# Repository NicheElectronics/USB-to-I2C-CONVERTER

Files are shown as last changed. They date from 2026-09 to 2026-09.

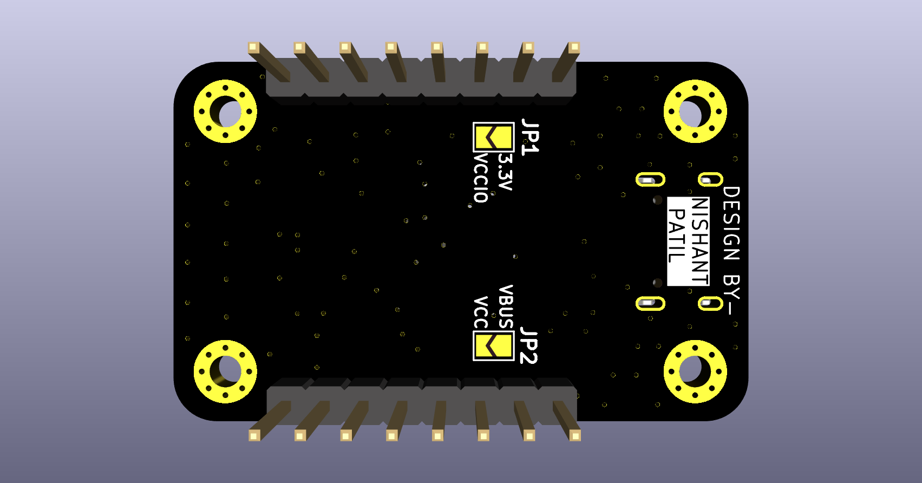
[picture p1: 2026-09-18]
hardware/pcb-design/renders/PCB-3D-Bottom.png

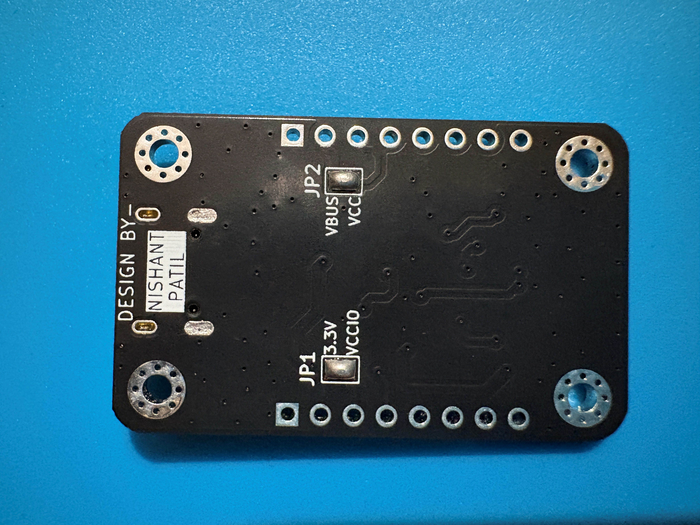
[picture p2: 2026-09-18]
validation/hardware/Assembled-PCB-Bottom.png

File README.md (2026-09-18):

# USB-to-I²C Converter | FT201X

A compact USB interface for an embedded system with an I²C master. The board uses an **FTDI FT201X** to exchange data between a USB host and a microcontroller or FPGA over I²C. Its USB Type-C connector provides the USB 2.0 connection to the computer.

> **Direction matters:** The FT201X is an **I²C slave**. It cannot act as an I²C master to scan or read sensors directly. Your microcontroller or FPGA initiates every I²C transfer.

## Project status

The PCB has been assembled and tested, according to the project notes. Specific measurements, firmware, and test logs have not been included here.

## How it works

```mermaid
flowchart TD
    PC["Computer / USB host"] <-->|"USB 2.0"| FT["FT201X · I²C slave"]
    FT <-->|"SDA + SCL"| MCU["MCU or FPGA · I²C master"]
    MCU <-->|"Shared I²C bus"| SENSOR["Other I²C devices"]
```

The master can address the FT201X and other slaves on the same bus, provided each slave has a unique address and the devices share compatible I/O levels. For example, to bring sensor readings to a PC, the MCU reads the sensor and writes the result to the FT201X; the FT201X sends those bytes over USB. The PC can send commands in the other direction for the MCU to read.

This is a **USB connection for an I²C-master system**, not a PC-controlled general-purpose I²C master adapter.

## Hardware overview

| Item | Implementation / purpose |
| --- | --- |
| Bridge | FTDI FT201X, USB 2.0 full speed to I²C slave |
| USB connector | USB Type-C, wired for USB 2.0 device operation |
| USB protection | ESD protection on D+ and D−; 27 Ω series resistors in the USB data paths |
| I²C connection | SDA and SCL with pull-up resistors; MCU/FPGA provides the clock |
| I/O supply | VCCIO sets the FT201X interface voltage; match it to the I²C bus |
| Other signals | Reset and configurable CBUS signals available on the board |
| Power | USB bus power with local decoupling and bulk capacitance |

The USB Type-C connection uses both orientations of D+ and D− and separate pull-down resistors on CC1 and CC2. Check the schematic for exact values, connector pinout, headers, and power options before connecting external hardware.

## I²C address and speed

- The FT201X factory-default **7-bit address is `0x22`**. An MCU library normally expects this 7-bit value, not the shifted address bytes (`0x44` for write and `0x45` for read).
- The address is configurable in FT201X nonvolatile settings, so check the programmed configuration if a scanner does not find `0x22`.
- Start bus bring-up at **100 kHz**; try **400 kHz** after basic transfers work. The FT201X supports faster I²C modes, but the selected rate and pull-ups must also work for every other device and the bus wiring.
- The USB serial port baud setting does **not** set the I²C clock. The I²C master generates SCL.

## Bring-up

1. With power off, check for shorts between supply and ground and confirm the intended VCCIO and pull-up voltage.
2. Connect USB and confirm the FT201X enumerates on the computer. Use FTDI's **FT_PROG** if you need to inspect its programmed settings.
3. Connect a common ground, SDA, and SCL to an I²C-master MCU. Avoid connecting an incompatible-voltage bus directly.
4. Set the MCU bus to 100 kHz and scan for the configured FT201X address (`0x22` by default).
5. Test bytes in **both** directions: PC → FT201X → MCU and MCU → FT201X → PC. Use the FT201X transfer protocol in the datasheet when writing firmware.
6. Add any sensors after the bridge works; check that their addresses do not conflict.

For PC-side testing, install the applicable FTDI driver. If the device appears as a virtual COM port, a serial terminal or `pyserial` can send and receive bytes. Define framing and commands in the MCU firmware; the FT201X does not automatically turn sensor data into text lines.

## If communication fails

| Symptom | Check |
| --- | --- |
| No USB device | USB cable and connector, VBUS, supply rails, reset, D+/D− wiring and ESD parts |
| No I²C acknowledgement | Master mode, common ground, SDA/SCL wiring, pull-ups, VCCIO, configured address |
| Intermittent transfers | Pull-up strength, bus capacitance, clock rate and shared-device loading |
| USB works but no sensor data | MCU firmware, FT201X read/write sequence and sensor address |

## Reference

- [FTDI FT201X product documentation](https://ftdichip.com/products/ft201xq/)

## Author

**Nishant Patil**

No license has been specified for the project files. Add a license file when you decide how others may use the design.

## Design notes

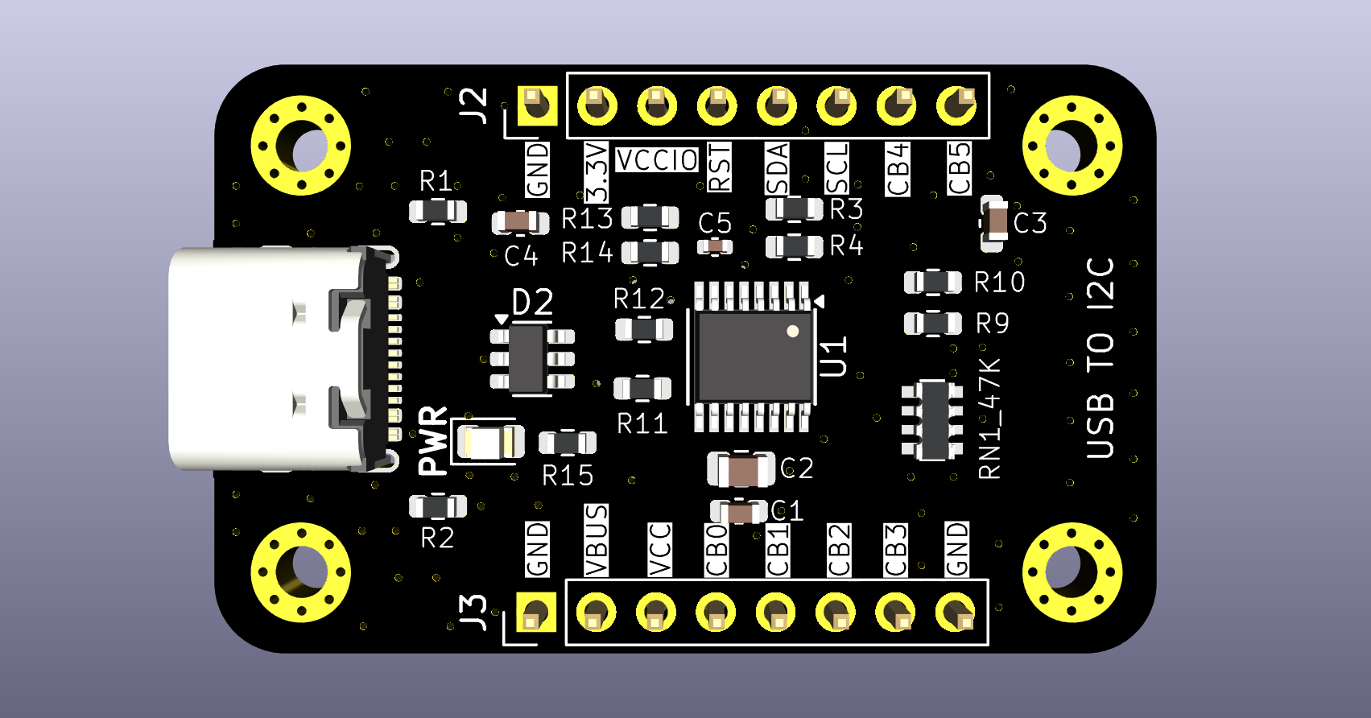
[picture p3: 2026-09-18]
hardware/pcb-design/renders/PCB-3D-Top.png

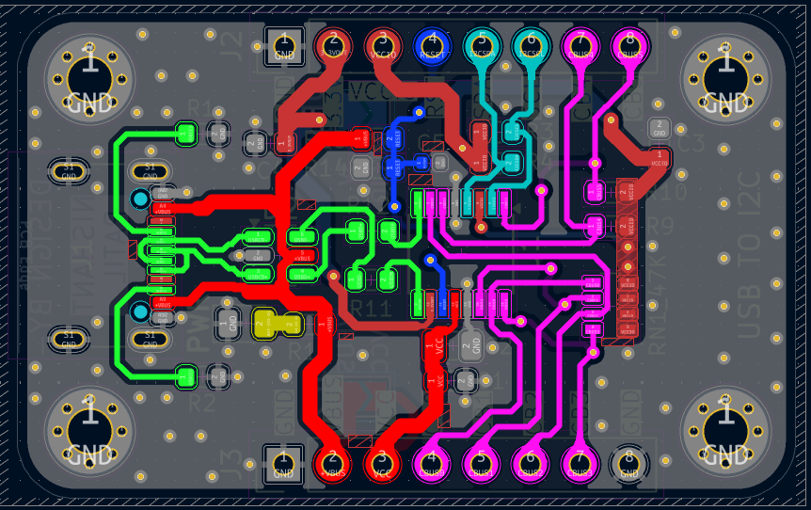
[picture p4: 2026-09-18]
hardware/pcb-design/layers/L1-Top-Signal-Power-GND-Pour.png

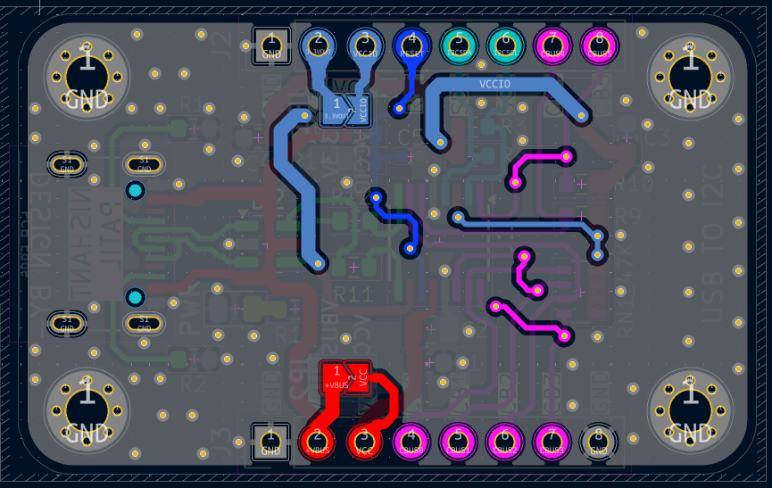
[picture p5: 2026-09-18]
hardware/pcb-design/layers/L2-Bottom-Signal-Power-GND-Pour.png

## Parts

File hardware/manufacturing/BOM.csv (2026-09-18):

Reference | Qty | Value | DNP | Exclude from BOM | Exclude from Board | Footprint | Datasheet
C1,C3,C4 | 3 | 0.1u |  |  |  | Capacitor_SMD:C_0603_1608Metric | ~
C2 | 1 | 4.7u |  |  |  | Capacitor_SMD:C_0805_2012Metric | ~
C5 | 1 | 10n |  |  |  | Capacitor_SMD:C_0402_1005Metric | ~
D1 | 1 | LED |  |  |  | LED_SMD:LED_0805_2012Metric | ~
D2 | 1 | USBLC6-2SC6 |  |  |  | Package_TO_SOT_SMD:SOT-23-6 | https://www.st.com/resource/en/datasheet/usblc6-2.pdf
H1,H2,H3,H4 | 4 | M2 |  | Excluded from BOM |  | MountingHole:MountingHole_2.2mm_M2_Pad_Via | ~
J1 | 1 | USB_C_Receptacle_USB2.0_16P |  |  |  | Connector_USB:USB_C_Receptacle_GCT_USB4105-xx-A_16P_TopMnt_Horizontal | https://www.usb.org/sites/default/files/documents/usb_type-c.zip
J2,J3 | 2 | Conn_01x08_Pin |  |  |  | Connector_PinHeader_2.54mm:PinHeader_1x08_P2.54mm_Vertical | ~
JP1,JP2 | 2 | Jumper_2_Open |  |  |  | Jumper:SolderJumper-2_P1.3mm_Open_TrianglePad1.0x1.5mm | ~
R1,R2 | 2 | 5K1 |  |  |  | Resistor_SMD:R_0603_1608Metric | ~
R3,R4 | 2 | 1K |  |  |  | Resistor_SMD:R_0603_1608Metric | ~
R9,R10 | 2 | 47K |  |  |  | Resistor_SMD:R_0603_1608Metric | ~
R11,R12 | 2 | 27R |  |  |  | Resistor_SMD:R_0603_1608Metric | ~
R13 | 1 | 10K |  |  |  | Resistor_SMD:R_0603_1608Metric | ~
R14 | 1 | 15K |  |  |  | Resistor_SMD:R_0603_1608Metric | ~
R15 | 1 | 270R |  |  |  | Resistor_SMD:R_0603_1608Metric | ~
RN1 | 1 | R_47K |  |  |  | Resistor_SMD:R_Array_Convex_4x0603 | ~
U1 | 1 | FT201XS |  |  |  | Package_SO:SSOP-16_3.9x4.9mm_P0.635mm | https://www.ftdichip.com/Support/Documents/DataSheets/ICs/DS_FT201X.pdf

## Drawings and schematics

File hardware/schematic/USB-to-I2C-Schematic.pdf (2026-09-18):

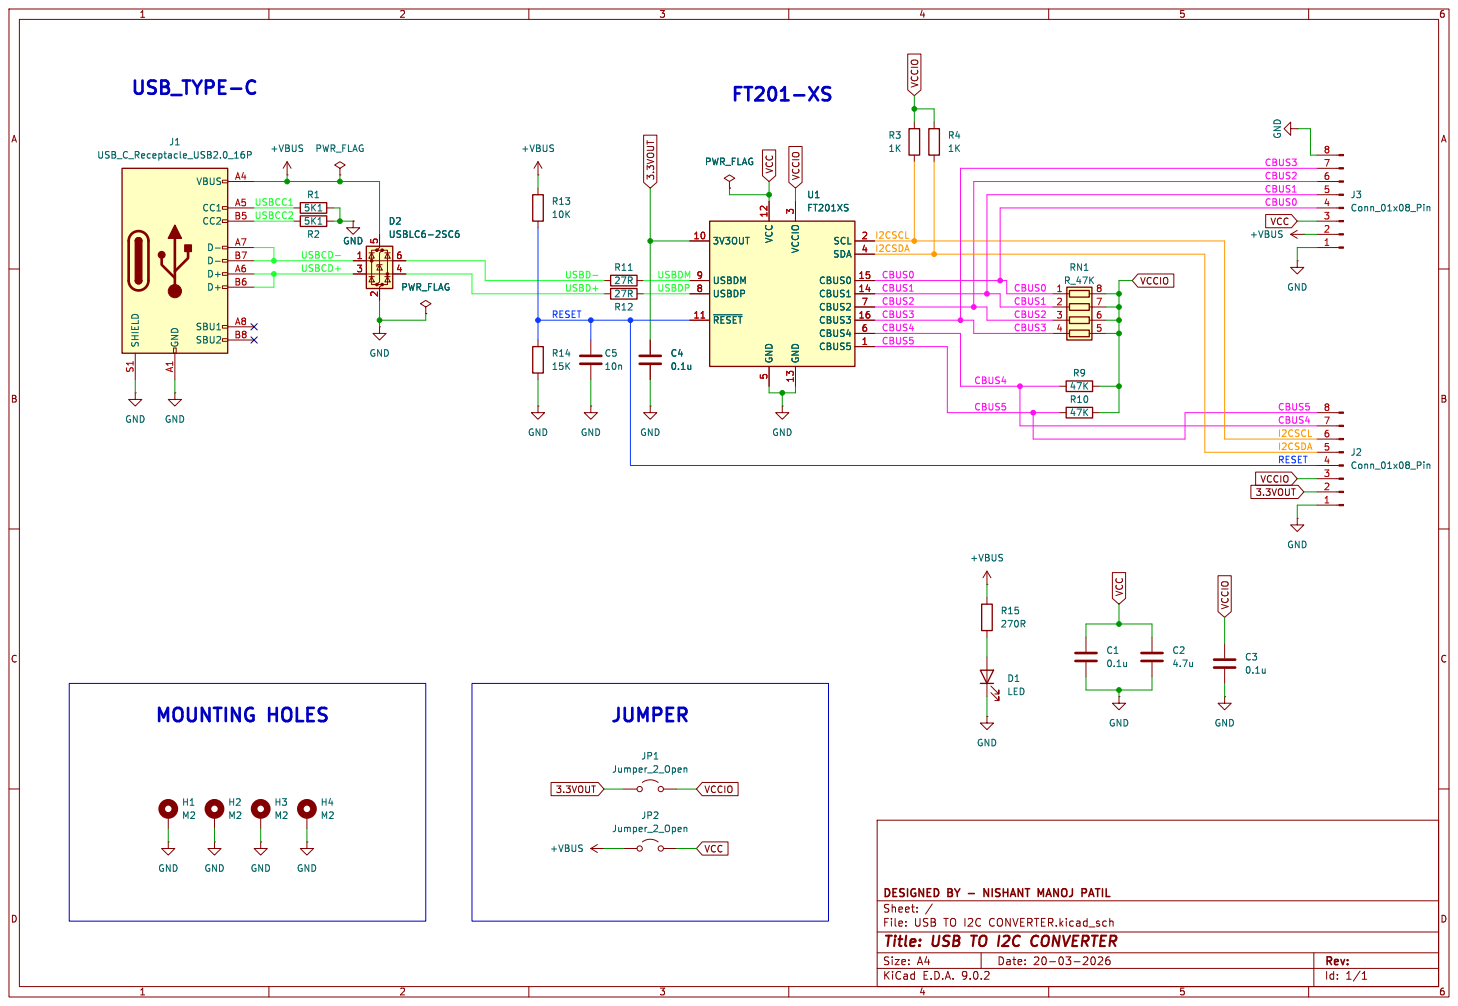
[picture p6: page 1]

3 GND 13 SCL 2 SDA 4 CBUS0 15 CBUS1 14 CBUS2 7 CBUS3 16 CBUS4 6 CBUS5 1 U1 FT201XS GND GND

Id: 1/1 Title: USB TO I2C CONVERTER

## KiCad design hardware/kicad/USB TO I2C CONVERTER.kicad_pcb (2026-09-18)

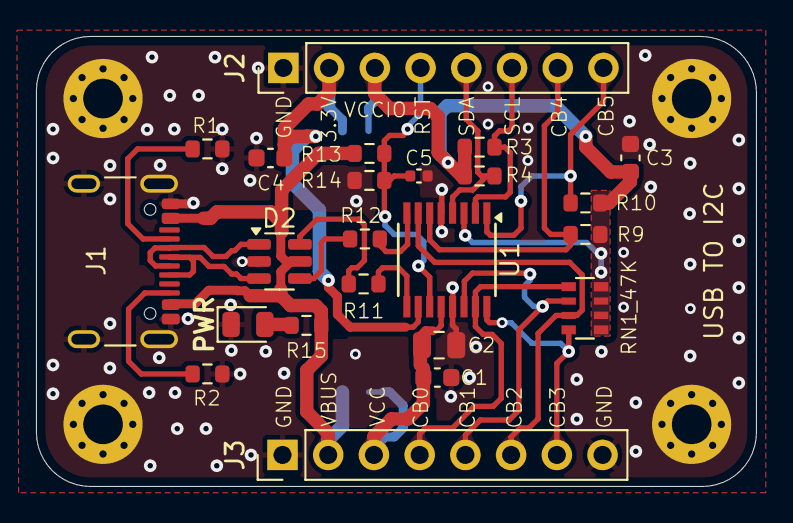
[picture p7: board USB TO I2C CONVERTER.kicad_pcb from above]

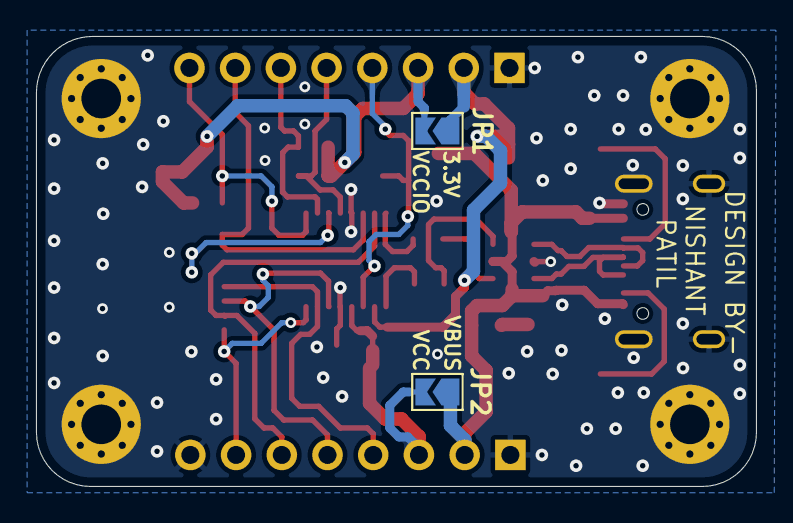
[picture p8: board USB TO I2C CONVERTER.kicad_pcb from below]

Board: 2 copper layers, 40.0 x 25.0 mm, 29 parts (2 on the bottom side), 23 nets.

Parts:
C1, C3, C4: 0.1u; C_0603_1608Metric
C2: 4.7u; C_0805_2012Metric
C5: 10n; C_0402_1005Metric
D2: USBLC6-2SC6; SOT-23-6
H1, H2, H3, H4: M2; MountingHole_2.2mm_M2_Pad_Via
J1: USB_C_Receptacle_USB2.0_16P; USB_C_Receptacle_GCT_USB4105-xx-A_16P_TopMnt_Horizontal
J2, J3: Conn_01x08_Pin; PinHeader_1x08_P2.54mm_Vertical
JP1, JP2: Jumper_2_Open; SolderJumper-2_P1.3mm_Open_TrianglePad1.0x1.5mm
PWR: LED; LED_0805_2012Metric
R1, R2: 5K1; R_0603_1608Metric
R3, R4: 1K; R_0603_1608Metric
R9, R10: 47K; R_0603_1608Metric
R11, R12: 27R; R_0603_1608Metric
R13: 10K; R_0603_1608Metric
R14: 15K; R_0603_1608Metric
R15: 270R; R_0603_1608Metric
RN1_47K: R_47K; R_Array_Convex_4x0603
U1: FT201XS; SSOP-16_3.9x4.9mm_P0.635mm

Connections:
3.3VOUT: C4.1, J2.2, JP1.1 (A), U1.10 (3V3OUT)
+VBUS: D2.5 (VBUS), J1.A4 (VBUS), J1.A9 (VBUS), J1.B4 (VBUS), J1.B9 (VBUS), J3.2, JP2.1 (A), R13.1, R15.1
/CBUS0: J3.4, RN1_47K.1 (R1.1), U1.15 (CBUS0)
/CBUS1: J3.5, RN1_47K.2 (R2.1), U1.14 (CBUS1)
/CBUS2: J3.6, RN1_47K.3 (R3.1), U1.7 (CBUS2)
/CBUS3: J3.7, RN1_47K.4 (R4.1), U1.16 (CBUS3)
/CBUS4: J2.7, R9.1, U1.6 (CBUS4)
/CBUS5: J2.8, R10.1, U1.1 (CBUS5)
/I2CSCL: J2.6, R3.2, U1.2 (SCL)
/I2CSDA: J2.5, R4.2, U1.4 (SDA)
/RESET: C5.1, J2.4, R13.2, R14.1, U1.11 (~RESET)
/USBCC1: J1.A5 (CC1), R1.1
/USBCC2: J1.B5 (CC2), R2.1
/USBCD+: D2.3 (I/O2), J1.A6 (D+), J1.B6 (D+)
/USBCD-: D2.1 (I/O1), J1.A7 (D-), J1.B7 (D-)
/USBD+: D2.4 (I/O2), R12.1
/USBD-: D2.6 (I/O1), R11.1
/USBDM: R11.2, U1.9 (USBDM)
/USBDP: R12.2, U1.8 (USBDP)
GND: C1.2, C2.2, C3.2, C4.2, C5.2, D2.2 (GND), H1.1, H2.1, H3.1, H4.1, J1.A1 (GND), J1.A12 (GND), J1.B1 (GND), J1.B12 (GND), J1.S1 (SHIELD), J2.1, J3.1, J3.8, PWR.1 (K), R1.2, R2.2, R14.2, U1.5 (GND), U1.13 (GND)
unnamed: PWR.2 (A), R15.2
VCC: C1.1, C2.1, J3.3, JP2.2 (B), U1.12 (VCC)
VCCIO: C3.1, J2.3, JP1.2 (B), R3.1, R4.1, R9.2, R10.2, RN1_47K.5 (R4.2), RN1_47K.6 (R3.2), RN1_47K.7 (R2.2), RN1_47K.8 (R1.2), U1.3 (VCCIO)

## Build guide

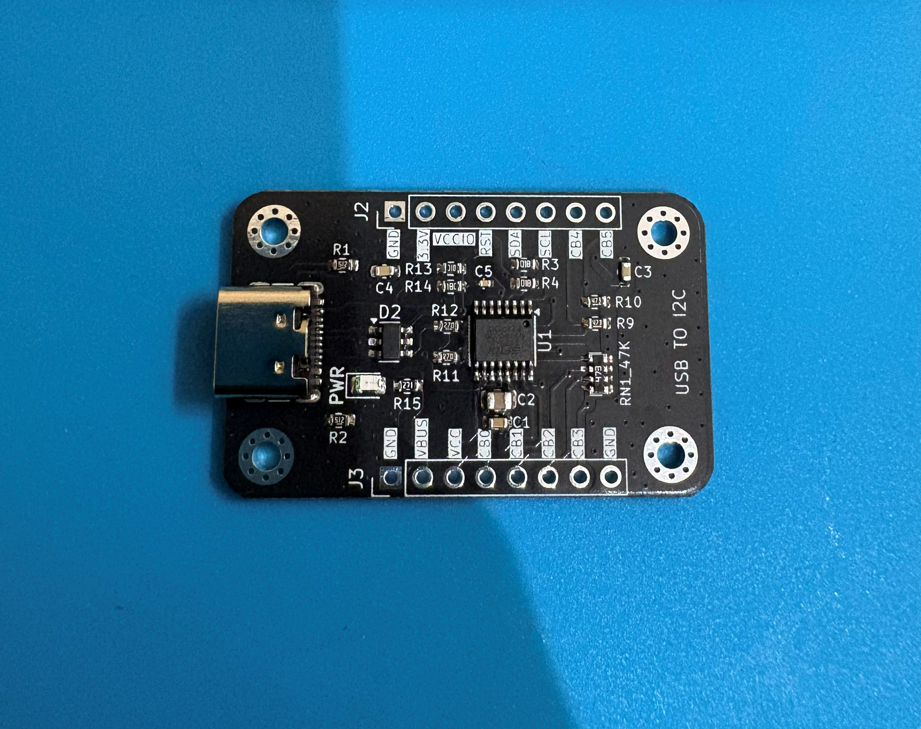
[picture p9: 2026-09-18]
validation/hardware/Assembled-PCB-Top.png
